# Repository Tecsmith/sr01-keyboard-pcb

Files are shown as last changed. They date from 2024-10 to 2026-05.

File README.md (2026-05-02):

# SR01-Keyboard-PCB

<p align="center">Under Construction</p>

> **Note:** Rev "D" is a full redo in KiCAD, and has not been tested -- so, not suitable to build just yet.

## Intent

The 1-key<small><sup>1</sup></small> *"keyboard"* development platform.

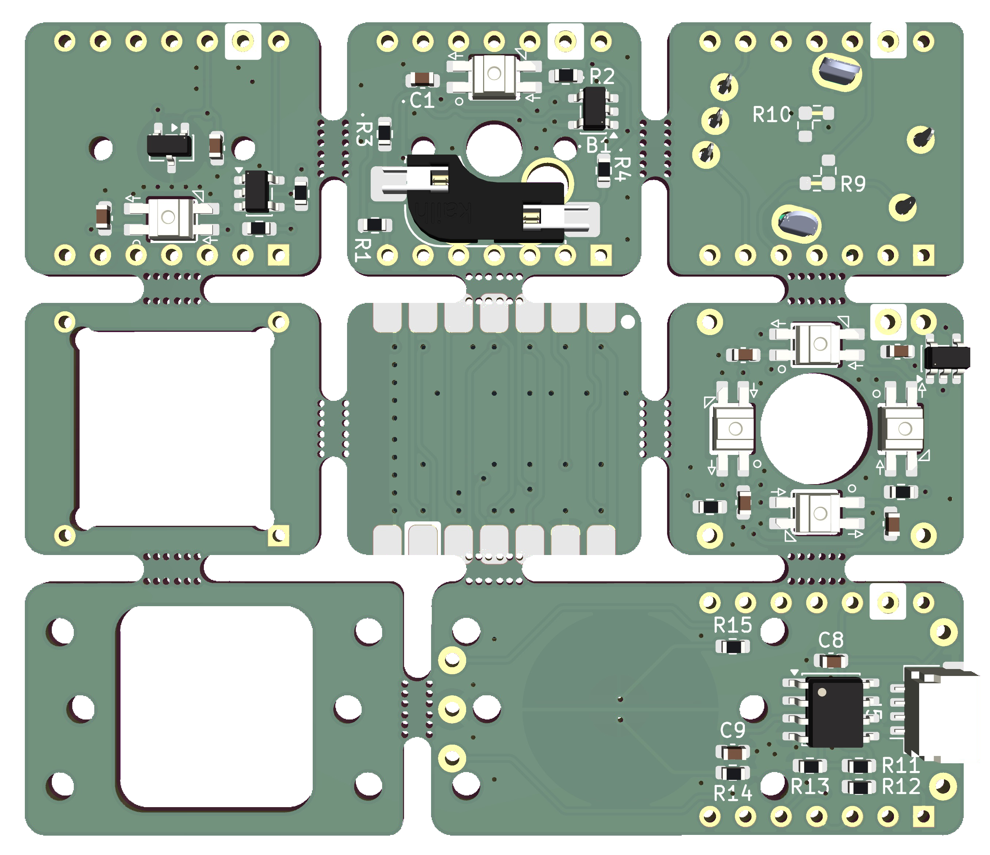
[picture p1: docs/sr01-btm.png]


## Features

This is not a "keyboard" per-se, it's a PCB that allows you you, with a **SeeedStudio** <a href="https://www.seeedstudio.com/XIAO-RP2040-v1-0-p-5026.html">XIAO RP2040</a> or <a href="https://www.seeedstudio.com/Seeed-XIAO-BLE-nRF52840-p-5201.html">XIAO nRF52840</a> module, to build:

* a 1-key MX-switch keyboard, with an RGB LED, <br>- *or* -
* a EC11 Rotary Encoder, with 4 RGB LED's, <br>- *or* -
* a 1-key HE *(Hall Effect)* switch keyboard, with a RGB LED, <br>- *or* -
* a 1-key EC *(Electrro Capacitance)* switch keyboard, <br> - *or* -
* a WHID solution, when *(the XIAO RP2040 is)* paired with a **SeeedStudio**:
  * <a href="https://www.seeedstudio.com/Seeed-Studio-XIAO-ESP32C6-p-5884.html">XIAO ESP32C6</a> module. [*Recommended*] , *- or -*
  * <a href="https://www.seeedstudio.com/Seeed-XIAO-ESP32C3-p-5431.html">XIAO ESP32C3</a> module, *- or -*
  * <a href="https://www.seeedstudio.com/XIAO-ESP32S3-p-5627.html">XIAO ESP32S3</a> module

for you to do some experimentations on.  These modules are intended to be breadboard mountable to that you can prototype your firmware and hardware ideas into verifiable solutions.

## Why?

When I built the SR61, one of the MicroMod modules I wanted to build for was the [SparkFun MicroMod ESP32 Processor](https://www.sparkfun.com/products/16781).. and for that I bought a [April Brother WHID Cactus](https://store.aprbrother.com/product/wifi-hid-injector) ... and then never got around to it.

The intent was to create a Wireless KB *(like a BT or 2.4GHz KB, but with WiFi)*, and also a whole bunch of additional features like a virtual web-KB, or the ability to configure the keys via it's own web interface.

This project is evolution of that idea.  *(The WHID Cactus is a ATmega 32u4 and ESP-12S combo. Old and limited.)*

And then the thought was: Why not also make it a Adafruit NeoKey Trinkey- / DigiSpark ATtiny85 USB key- ... -like one key?

Anyway ... what came out is a platform to build 1-key solutions for testing features, or just to have a quick volume control / sleep keep-alive / whatever you want to **play** with ... [*Software examples TBA*]

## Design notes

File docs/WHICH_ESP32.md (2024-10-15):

# ESP32 Microcontroller Comparison 

| Feature | ESP32 | ESP32-C2 | ESP32-C3 | ESP32-C6 | ESP32-S2 | ESP32-S3 |
|---|---|---|---|---|---|---|
| Core Architecture | Dual-core Xtensa LX6 | Single-core RISC-V | Single-core RISC-V | Single-core RISC-V | Single-core Xtensa LX7 | Dual-core Xtensa LX7 |
| WiFi Standard | 802.11 b/g/n | 802.11 b/g/n | 802.11 b/g/n | 802.11 b/g/n/ax | 802.11 b/g/n | 802.11 b/g/n |
| Bluetooth | v4.2 (Classic + BLE) | No | BLE only (v5.0) | BLE only (v5.0) | No | v5.0 (Classic + BLE) |
| Flash Memory | External Flash (varies)  | 4MB (varies by model) | 4MB (varies by model) | 4MB (varies by model) | 4MB (varies by model) | 4MB (varies by model) |
| PSRAM Support | Optional | No | No | No | No | Yes (varies by model) |
| GPIO Pins | 34 | 20 | 22 | 22 | 43 | 45 |
| USB Support | No | No | Yes (USB-CDC) | Yes (USB-CDC) | Yes (USB-OTG) | Yes (USB-OTG) |
| CPU Speed | 240 MHz | 160 MHz | 160 MHz | 160 MHz | 240 MHz | 240 MHz |
| Security Features | Secure Boot, Flash Encryption | Secure Boot, Flash Encryption | Secure Boot, Flash Encryption | Secure Boot, Flash Encryption, WPA3 | Secure Boot, Flash Encryption | Secure Boot, Flash Encryption, AES acceleration |
| Ultra-Low Power Mode (ULP) | Yes | Yes | Yes | Yes | Yes | Yes |
| Temperature Range | -40°C to 85°C | -40°C to 125°C | -40°C to 125°C | -40°C to 125°C | -40°C to 85°C | -40°C to 85°C |
| Peripherals | ADC, DAC, PWM, I2C, SPI, UART | ADC, PWM, I2C, SPI, UART | ADC, PWM, I2C, SPI, UART | ADC, PWM, I2C, SPI, UART | ADC, DAC, PWM, I2C, SPI, UART | ADC, DAC, PWM, I2C, SPI, UART |
| Target Applications | General IoT, Wearables | Simple IoT Devices | Battery-powered IoT Devices | IoT with WiFi 6, Low Power | WiFi Security Cameras, Sensor Nodes | AI Vision, Speech Processing |

### Summary
- **ESP32**:    Dual-core MCU used in various modules like ESP32-WROOM-32, ideal for general-purpose IoT and Bluetooth applications.
- **ESP32-C2**: RISC-V based MCU targeting simple IoT applications, focusing on cost-effectiveness with basic WiFi support.
- **ESP32-C3**: RISC-V based MCU focused on low power and cost-efficiency, great for battery-powered and BLE-only projects.
- **ESP32-C6**: RISC-V based MCU with WiFi 6 support, ideal for modern IoT applications requiring better WiFi performance and security.
- **ESP32-S2**: Single-core MCU with USB-OTG support and lower power consumption, suitable for sensor hubs and security applications.
- **ESP32-S3**: Dual-core MCU with AI capabilities, enhanced GPIO, and support for vision and speech recognition projects.

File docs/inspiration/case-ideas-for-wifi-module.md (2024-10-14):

# Case ideas for WiFi variant

## If only these frag'in guys published their PCB dims!!!

- https://aliexpress.com/item/1917141063.html
- https://aliexpress.com/item/1005005003350503.html
- https://aliexpress.com/item/1005005215066562.html
- https://aliexpress.com/item/1005005966081850.html
- https://aliexpress.com/item/1005003831368419.html
- https://aliexpress.com/item/1005006605218104.html
- https://aliexpress.com/item/1005007033009640.html

## Let's see if this one works?

- https://aliexpress.com/item/1005005717059111.html

Wider one:

- https://aliexpress.com/item/1005003834640869.html

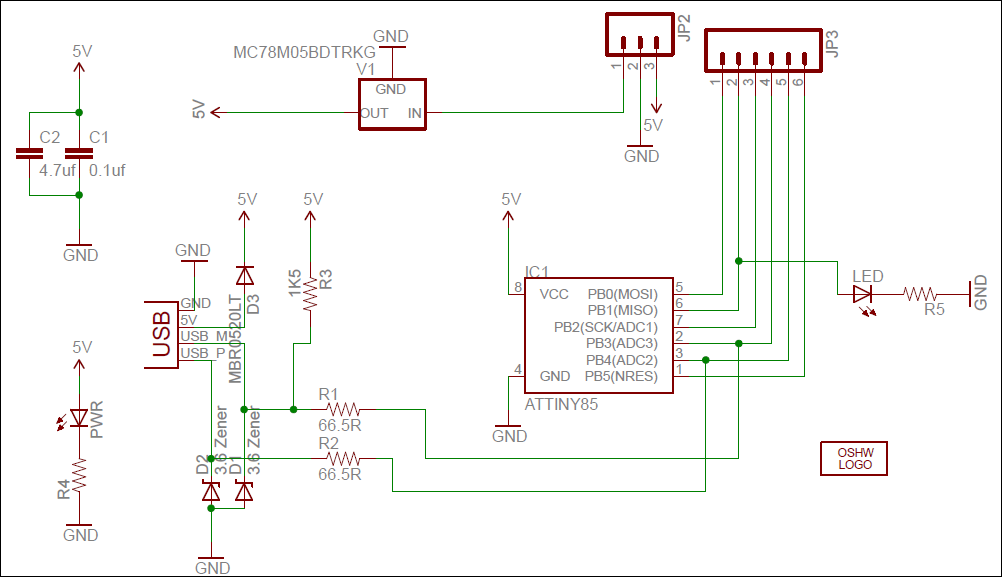
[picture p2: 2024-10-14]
docs/inspiration/digispark/digispark-schematic.png

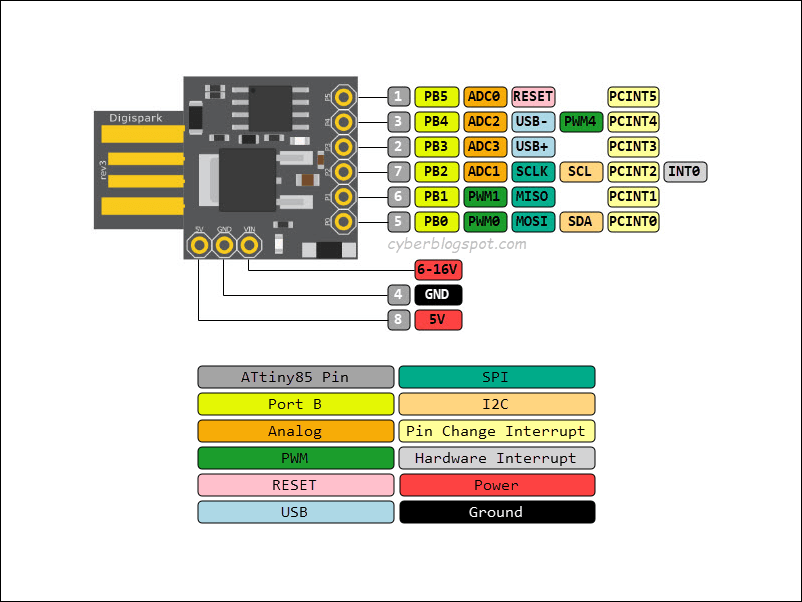
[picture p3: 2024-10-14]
docs/inspiration/digispark/digispark-attiny85-pinout-original_final.png

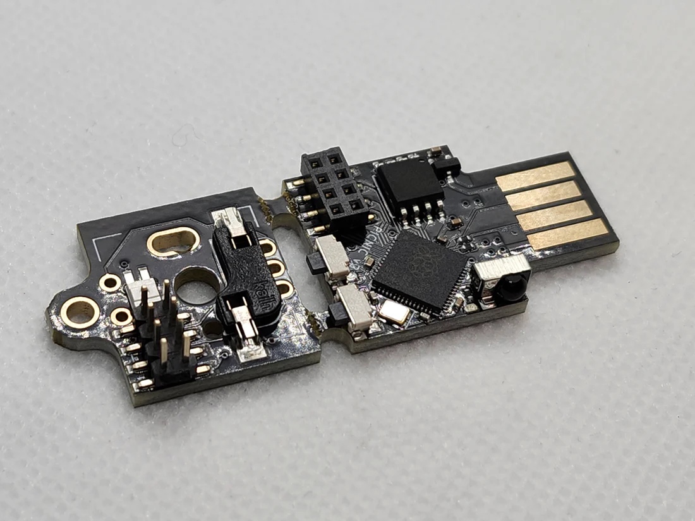
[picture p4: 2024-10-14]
docs/inspiration/snipeye-uno/uno6.jpg

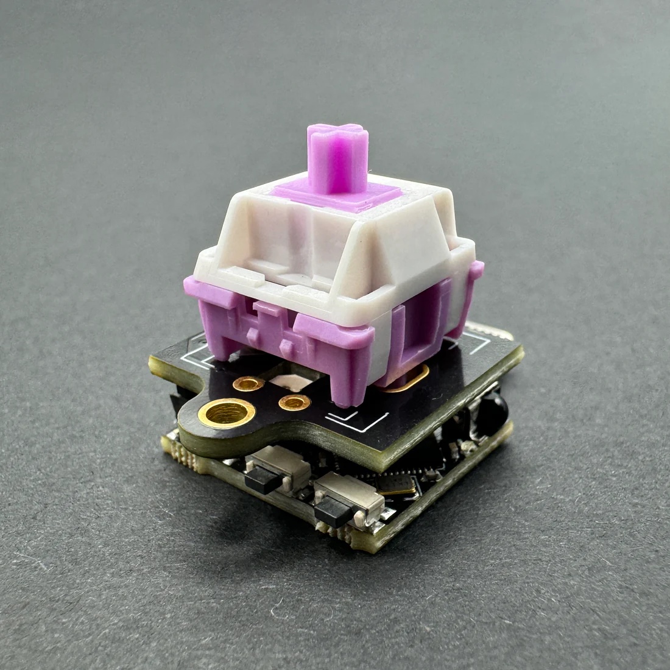
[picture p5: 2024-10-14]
docs/inspiration/snipeye-uno/uno2.jpg

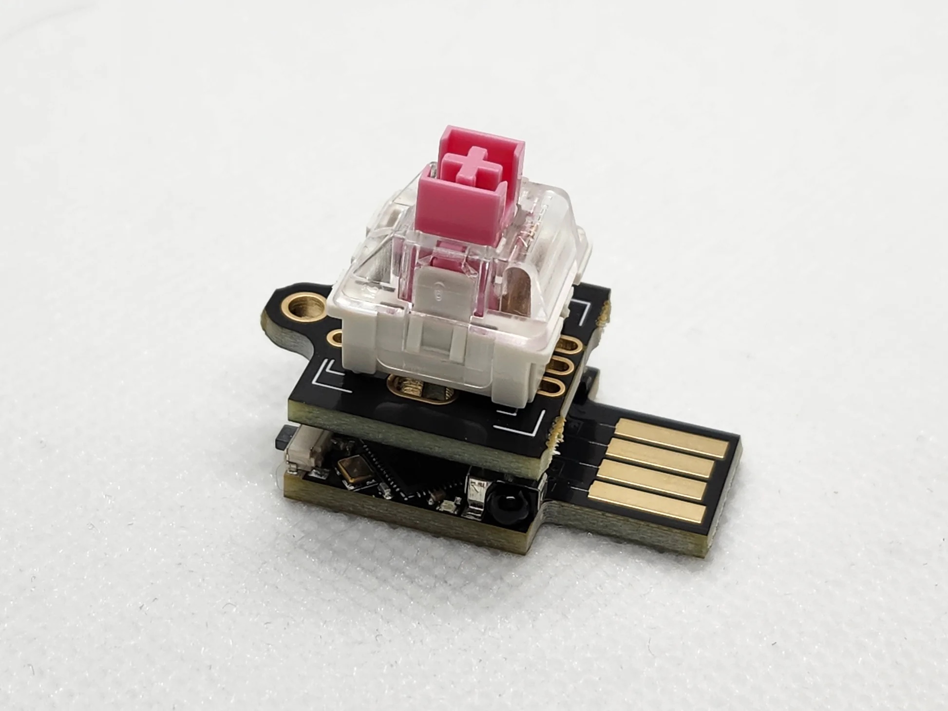
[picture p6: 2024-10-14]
docs/inspiration/snipeye-uno/uno8.jpg

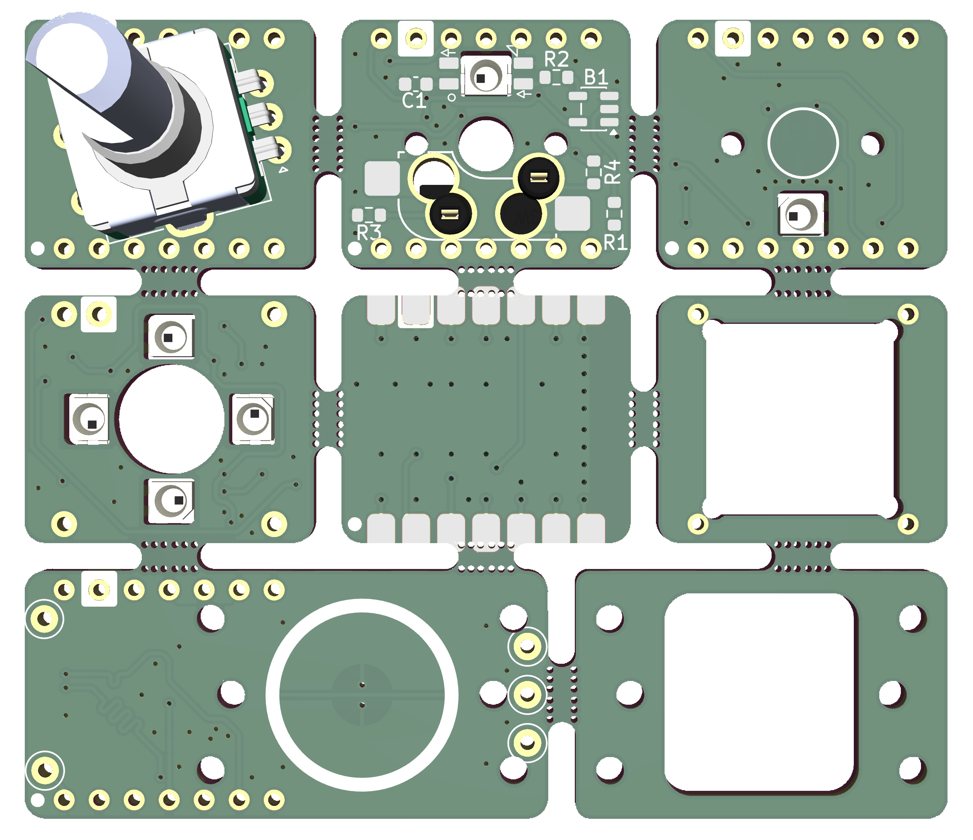
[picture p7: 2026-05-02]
docs/sr01-top.png

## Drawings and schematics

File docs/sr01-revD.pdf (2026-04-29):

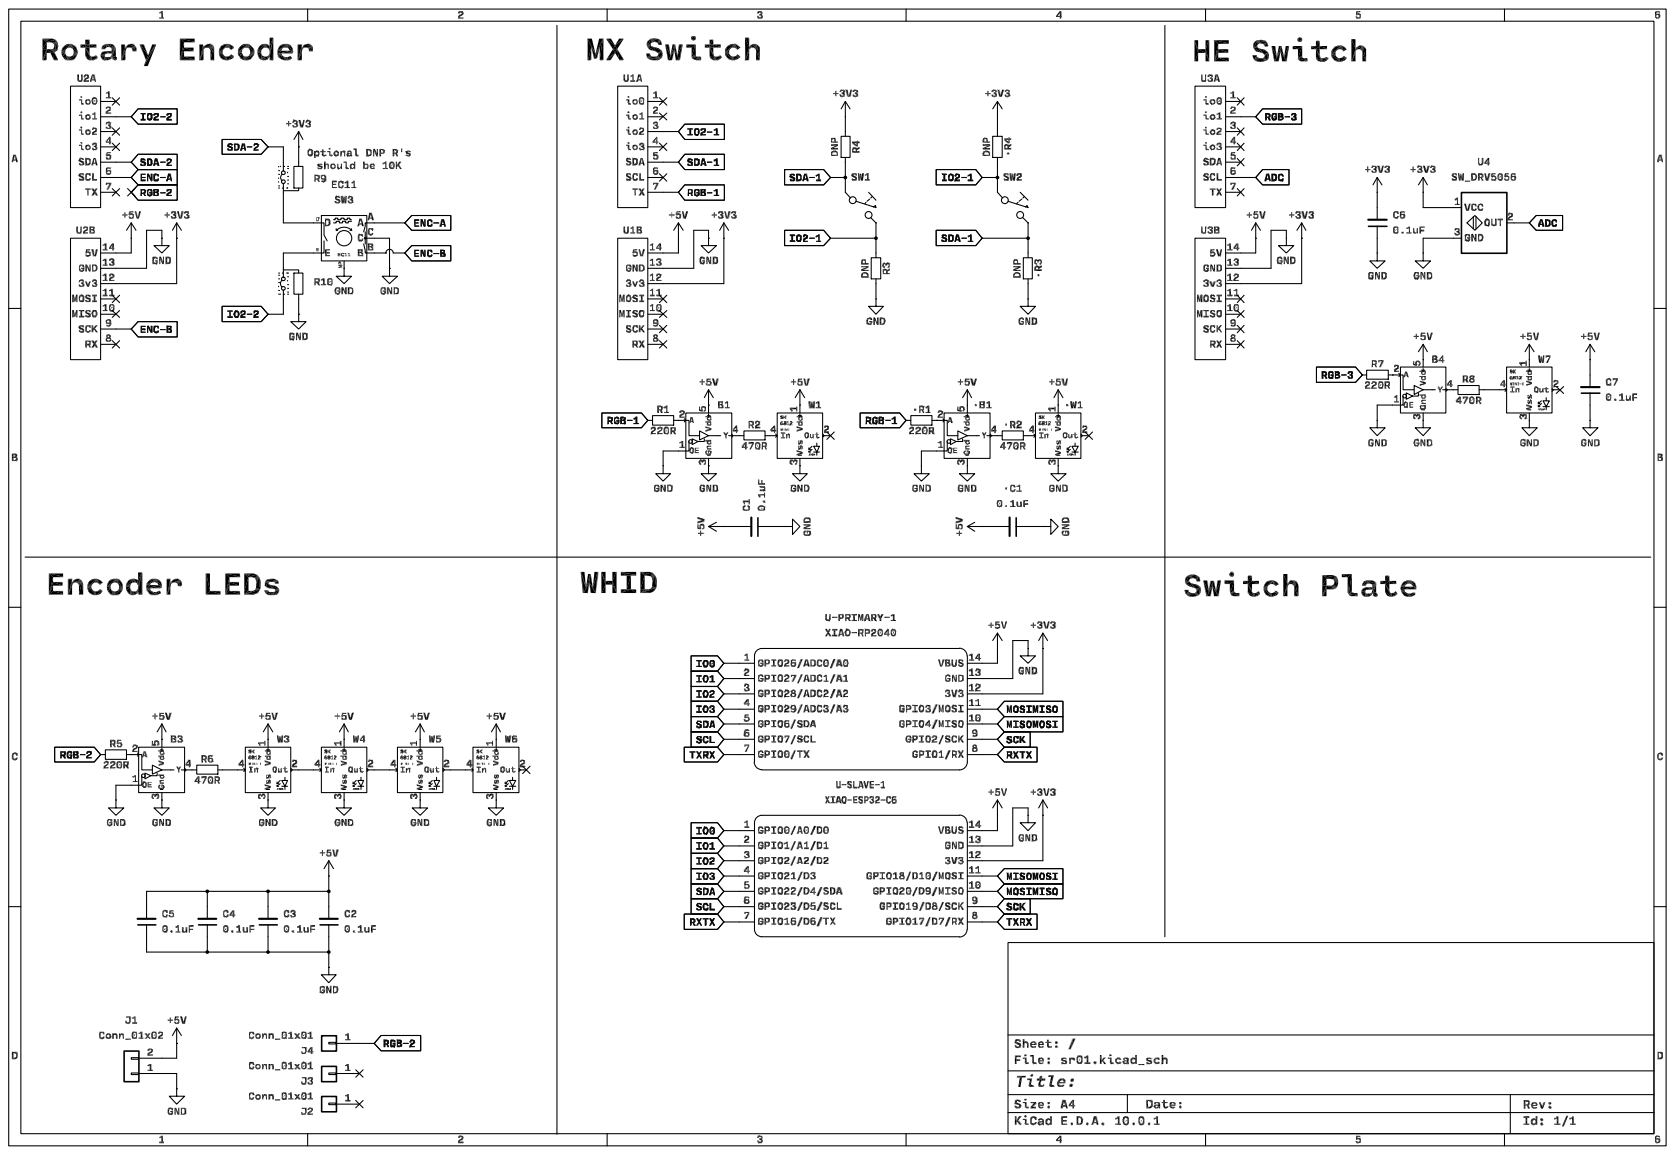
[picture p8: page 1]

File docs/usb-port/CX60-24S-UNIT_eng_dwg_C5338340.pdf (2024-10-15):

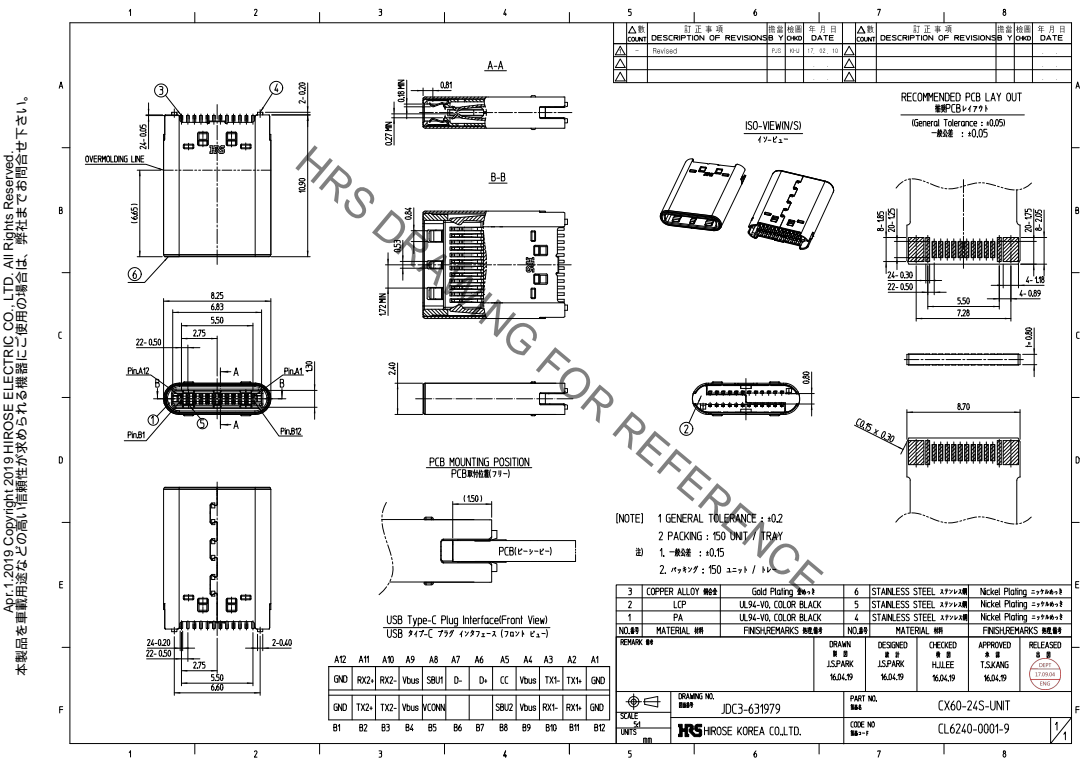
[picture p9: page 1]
本製品を車載用途などの高い信頼性が求められる機器にご使用の場合は、弊社までお問合せ下さい。

HRS DRAWING FOR REFERENCE

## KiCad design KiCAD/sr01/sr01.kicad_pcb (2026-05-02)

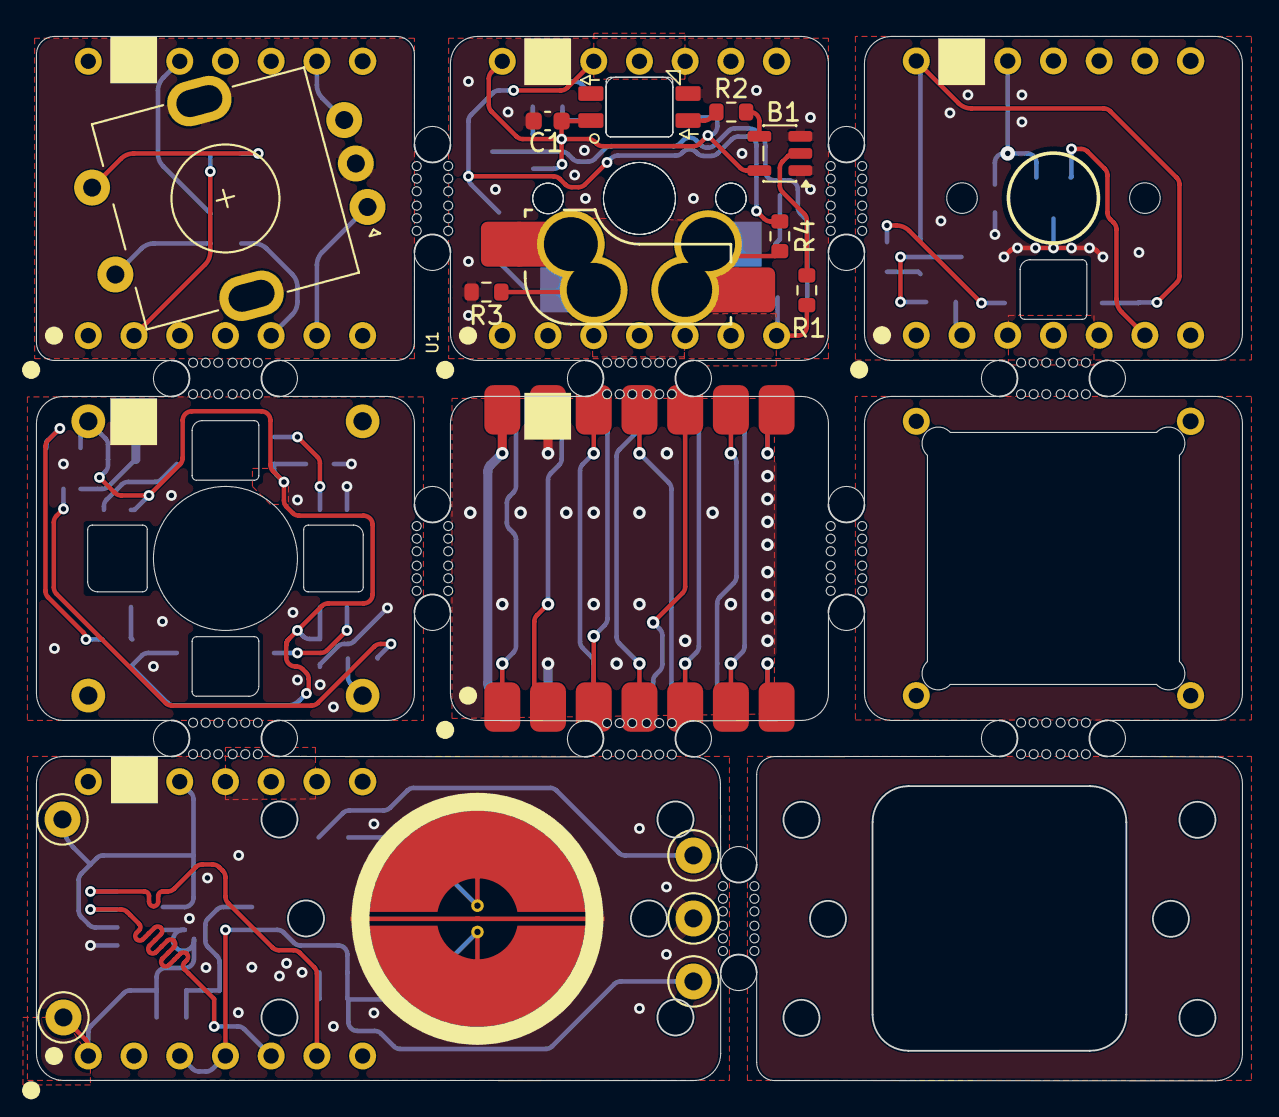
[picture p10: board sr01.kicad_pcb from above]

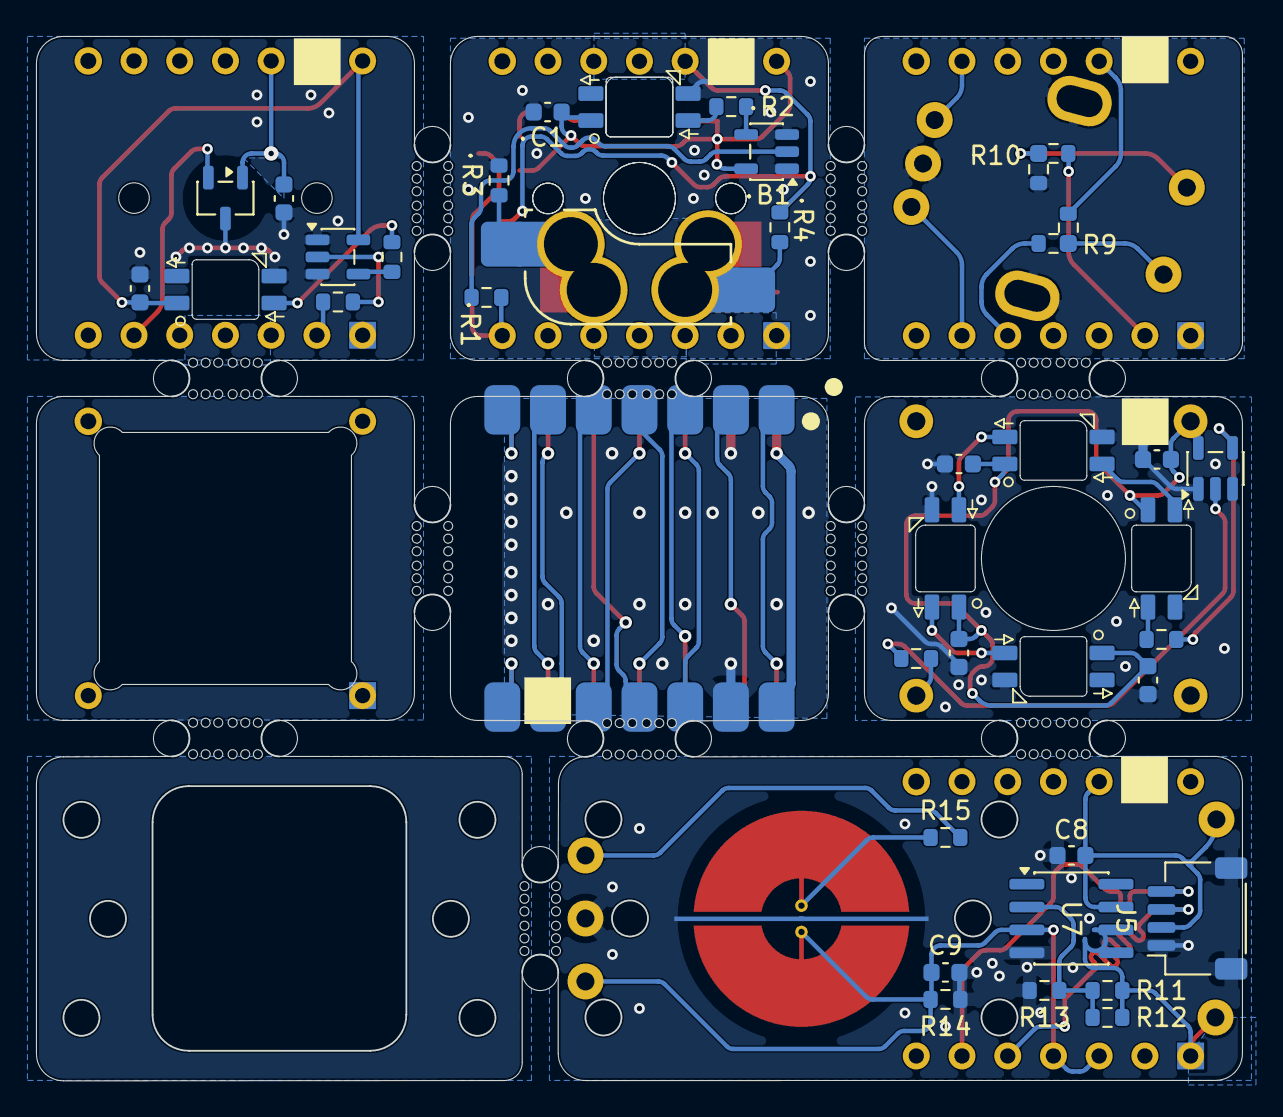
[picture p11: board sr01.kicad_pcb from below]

Board: 2 copper layers, 67.0 x 58.0 mm, 73 parts (39 on the bottom side), 48 nets.

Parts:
B1, B3, B4: SOT-23-5
C1, C2, C3, C4, C5, C6, C7, C8: 0.1uF; C_0603_1608Metric
C9: 220p; C_0603_1608Metric
J1: Conn_01x02; 1x02_P2.54mm
J2, J3, J4: Conn_01x01; 1x01_P2.54mm
J5: JST_SH_SM04B-SRSS-TB_1x04-1MP_P1.00mm_Horizontal
R1, R5, R7: 220R; R_0603_1608Metric
R2, R6, R8: 470R; R_0603_1608Metric
R3, R4, R12: DNP; R_0603_1608Metric
R9, R10: Jumper_R_0603_Short
R11, R14: 100K; R_0603_1608Metric
R13: 1K; R_0603_1608Metric
R15: 100R; R_0603_1608Metric
SW1, SW2: SW_MX_HotSwap
SW3: EC11; EC11-E
TP1, TP2, TP3, TP4, TP5: TestPoint_Keystone_5000-5004_Miniature
U1, U2, U3, U5: XIAO-Generic-DIP
U4: SW_DRV5056; SW_HE_DRV5056
U6: SW_EC_1U
U7: OPA350; SOIC-8_3.9x4.9mm_P1.27mm
U-PRIMARY-1: XIAO-RP2040; XIAO-Generic-SMD
U-SLAVE-1: XIAO-ESP32-C6; XIAO-Generic-SMD
W1, W3, W4, W5, W6, W7: SK6812MINI-E
mouse-bite-2mm-slot, mouse-bite-2mm-slot#2, mouse-bite-2mm-slot#3, mouse-bite-2mm-slot#4, mouse-bite-2mm-slot#5, mouse-bite-2mm-slot#6, mouse-bite-2mm-slot#7, mouse-bite-2mm-slot#8, mouse-bite-2mm-slot#9, mouse-bite-2mm-slot#10, mouse-bite-2mm-slot#11: VAL**; mouse-bite-2mm-slot
·B1: SOT-23-5
·C1: 0.1uF; C_0603_1608Metric
·R1: 220R; R_0603_1608Metric
·R2: 470R; R_0603_1608Metric
·R3, ·R4: DNP; R_0603_1608Metric
·W1: SK6812MINI-E

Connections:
+3V3: C6.2, C8.2, J5.2, R4.2, R9.3, TP5.1, U1.12 (3v3), U2.12 (3v3), U3.12 (3v3), U4.1 (VCC), U5.12 (3v3), U7.7 (V+), U-PRIMARY-1.12 (3V3), U-SLAVE-1.12 (3V3), ·R4.2
+5V: B1.5 (Vdd), B3.5 (Vdd), B4.5 (Vdd), C1.2, C2.2, C3.2, C4.2, C5.2, C7.2, J1.2, U1.14 (5V), U2.14 (5V), U3.14 (5V), U5.14 (5V), U-PRIMARY-1.14 (VBUS), U-SLAVE-1.14 (VBUS), W1.1 (Vdd), W3.1 (Vdd), W4.1 (Vdd), W5.1 (Vdd), W6.1 (Vdd), W7.1 (Vdd), ·B1.5 (Vdd), ·C1.2, ·W1.1 (Vdd)
ADC1: U3.6 (SCL), U4.2 (OUT)
ADC2: R11.1, R12.1, TP3.1, U5.1 (io0), U7.6 (Out)
COL: C9.2, R14.1, TP1.1, U5.3 (io2), U5.4 (io3), U6.1, U7.3 (In+)
ENC-A: SW3.A, U2.6 (SCL)
ENC-B: SW3.B, U2.9 (SCK)
GND: B1.1 (~OE), B1.3 (Gnd), B3.1 (~OE), B3.3 (Gnd), B4.1 (~OE), B4.3 (Gnd), C1.1, C2.1, C3.1, C4.1, C5.1, C6.1, C7.1, C8.1, C9.1, J1.1, J5.1, J5.MP, R3.1, R10.3, R13.2, R14.2, SW3.C, SW3.MP, TP4.1, U1.13 (GND), U2.13 (GND), U3.13 (GND), U4.3 (GND), U5.13 (GND), U6.3, U7.4 (V-), U-PRIMARY-1.13 (GND), U-SLAVE-1.13 (GND), W1.3 (Vss), W3.3 (Vss), W4.3 (Vss), W5.3 (Vss), W6.3 (Vss), W7.3 (Vss), ·B1.1 (~OE), ·B1.3 (Gnd), ·C1.1, ·R3.1, ·W1.3 (Vss)
IO0: U-PRIMARY-1.1 (GPIO26/ADC0/A0), U-SLAVE-1.1 (GPIO0/A0/D0)
IO1: U-PRIMARY-1.2 (GPIO27/ADC1/A1), U-SLAVE-1.2 (GPIO1/A1/D1)
IO2: U-PRIMARY-1.3 (GPIO28/ADC2/A2), U-SLAVE-1.3 (GPIO2/A2/D2)
IO2-1: R3.2, SW1.2, SW2.1, U1.3 (io2), ·R4.1
IO2-2: R10.2, U2.2 (io1)
IO3: U-PRIMARY-1.4 (GPIO29/ADC3/A3), U-SLAVE-1.4 (GPIO21/D3)
MISOMOSI: U-PRIMARY-1.10 (GPIO4/MISO), U-SLAVE-1.11 (GPIO18/D10/MOSI)
MOSIMISO: U-PRIMARY-1.11 (GPIO3/MOSI), U-SLAVE-1.10 (GPIO20/D9/MISO)
unnamed: B1.2 (A), R1.1
unnamed: B1.4 (Y), R2.2
unnamed: B3.2 (A), R5.1
unnamed: B3.4 (Y), R6.2
unnamed: B4.2 (A), R7.1
unnamed: B4.4 (Y), R8.2
unnamed: R9.1, SW3.D
unnamed: R10.1, SW3.E
unnamed: R15.2, U6.2
unnamed: R11.2, R12.2, R13.1, U7.2 (In-)
unnamed: R2.1, W1.4 (In)
unnamed: R6.1, W3.4 (In)
unnamed: W3.2 (Out), W4.4 (In)
unnamed: W4.2 (Out), W5.4 (In)
unnamed: W5.2 (Out), W6.4 (In)
unnamed: R8.1, W7.4 (In)
unnamed: ·B1.2 (A), ·R1.1
unnamed: ·B1.4 (Y), ·R2.2
unnamed: ·R2.1, ·W1.4 (In)
RGB-1: R1.2, U1.7 (TX), ·R1.2
RGB-2: J4.1 (Pin_1_1), R5.2
RGB-3: R7.2, U3.2 (io1)
ROW: R15.1, TP2.1
RXTX: U-PRIMARY-1.8 (GPIO1/RX), U-SLAVE-1.7 (GPIO16/D6/TX)
SCK: U-PRIMARY-1.9 (GPIO2/SCK), U-SLAVE-1.9 (GPIO19/D8/SCK)
SCL: U-PRIMARY-1.6 (GPIO7/SCL), U-SLAVE-1.6 (GPIO23/D5/SCL)
SCL2: J5.4, U5.6 (SCL)
SDA: U-PRIMARY-1.5 (GPIO6/SDA), U-SLAVE-1.5 (GPIO22/D4/SDA)
SDA2: J5.3, U5.5 (SDA)
SDA-1: R4.1, SW1.1, SW2.2, U1.5 (SDA), ·R3.2
SDA-2: R9.2, U2.5 (SDA)
TXRX: U-PRIMARY-1.7 (GPIO0/TX), U-SLAVE-1.8 (GPIO17/D7/RX)

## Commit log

2024-12-07 Rev C PCB
    [vr01-revA.brd, vr01-revA.sch, vr01-revC.brd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]
2026-04-29 Added KiCAD redo -- rev D
    [sr01-revC.brd, sr01-revC.sch, sr01.kicad_pcb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]
2026-05-02 add EC switch
    [sr01.kicad_pcb, sr01.kicad_sch]
